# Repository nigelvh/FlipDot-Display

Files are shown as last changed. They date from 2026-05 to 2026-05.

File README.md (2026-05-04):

# FlipDot Display Driver
A driver for a flipdot display I found on eBay. Unfortunately I haven't found what the make/model of the display is. The design was based entirely on reverse engineering the connections.

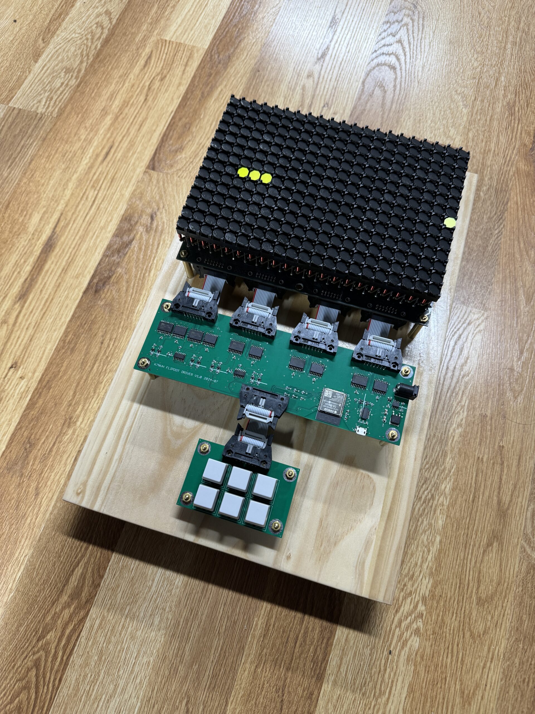
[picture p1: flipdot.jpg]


## Hardware
These are the hardware design files. They're almost certainly terrible. Replicate this device at your own peril.

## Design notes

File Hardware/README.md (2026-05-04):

# Hardware Design
There are two custom PCBs I designed for this project, one simple one just supporting the input buttons, and the other that contains the actual logic and drivers for the flipdot panel.

The ESP32 handles all of the logic for the display, and feeds into the driver shift registers.

The drivers are MIC5841 (Low Side) and MIC5891 (High Side) devices, there's three pairs covering the 21 columns, and then two pairs covering the 14 rows. There are NAND gates on each set that provide an interlock preventing both the high side and low side drivers being active at the same time.

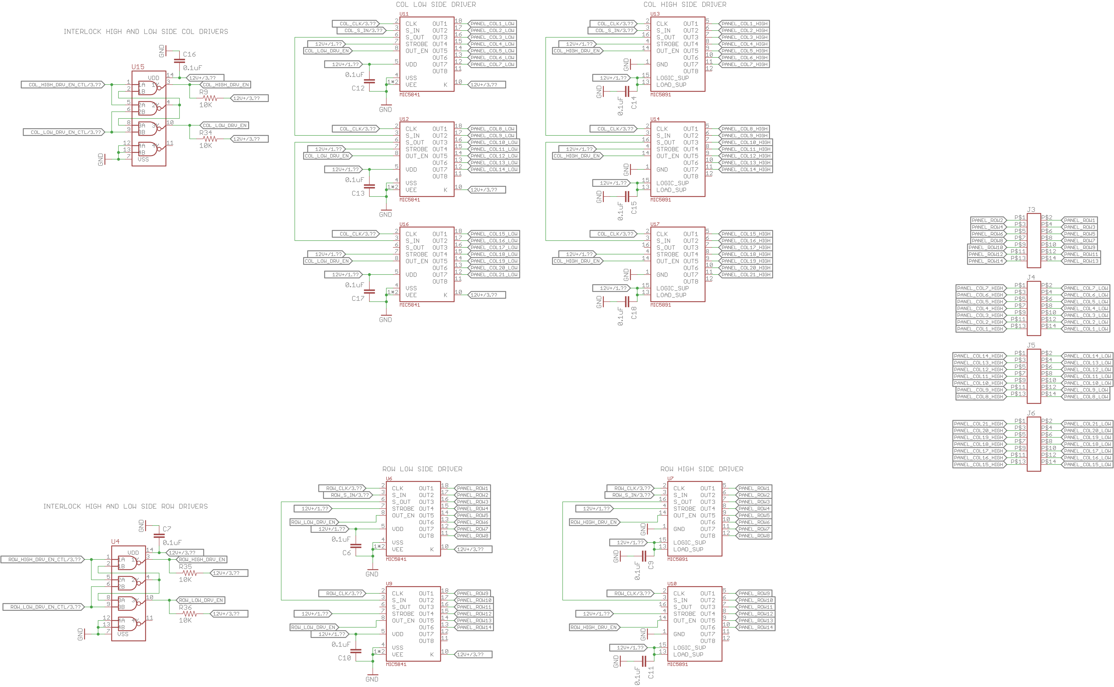
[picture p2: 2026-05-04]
Hardware/Driver/Driver_Schematic_Drivers.png

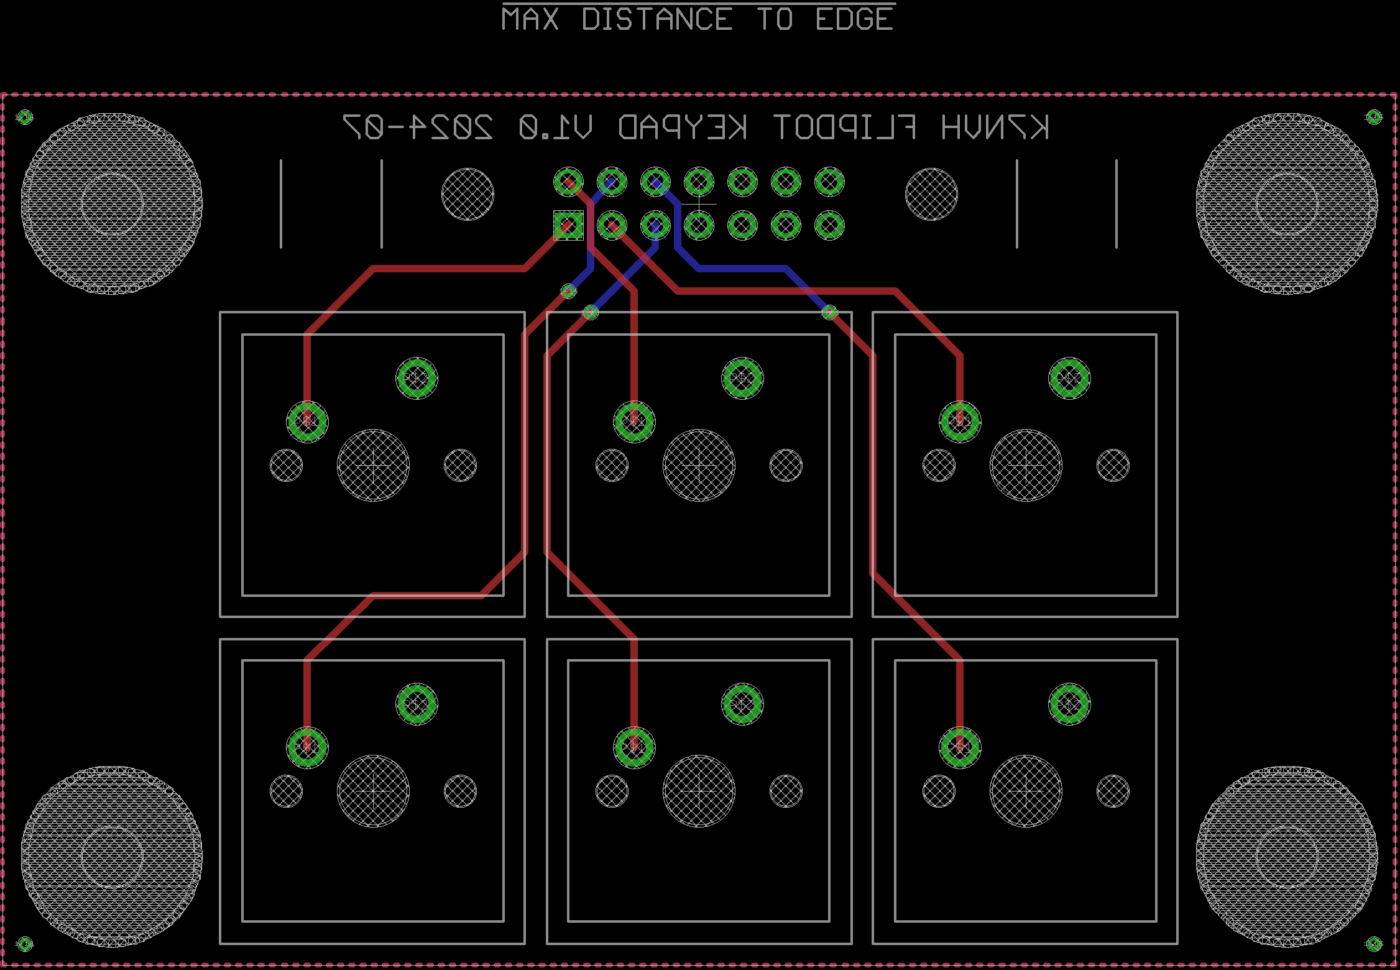
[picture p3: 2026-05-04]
Hardware/Buttons/Button_Board.png

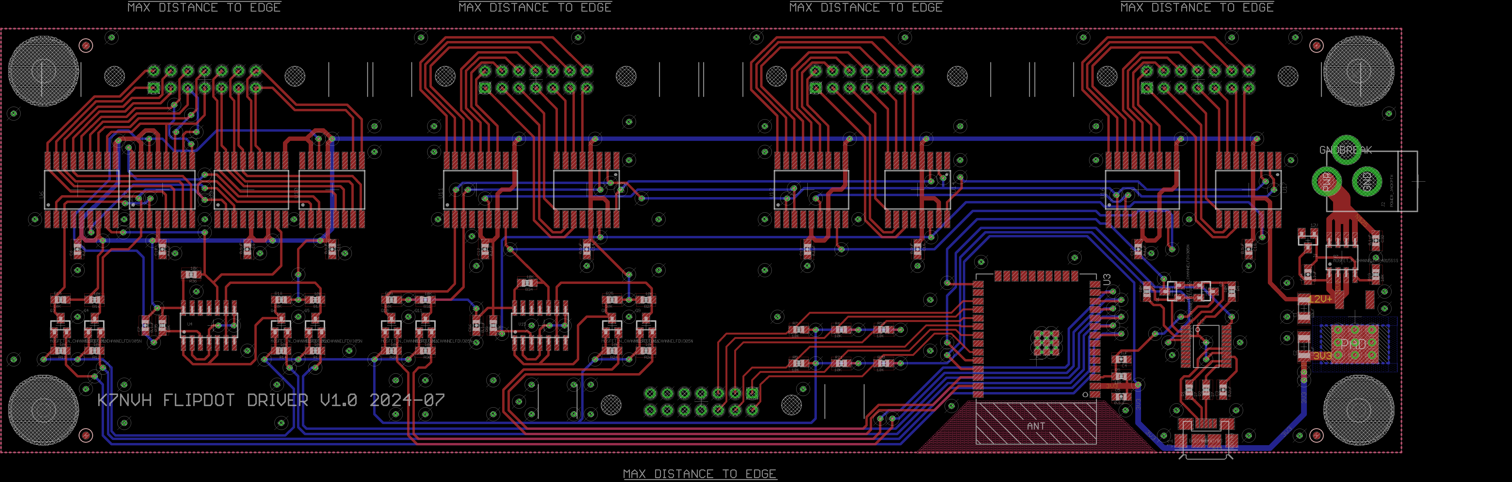
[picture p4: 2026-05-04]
Hardware/Driver/Driver_Board.png

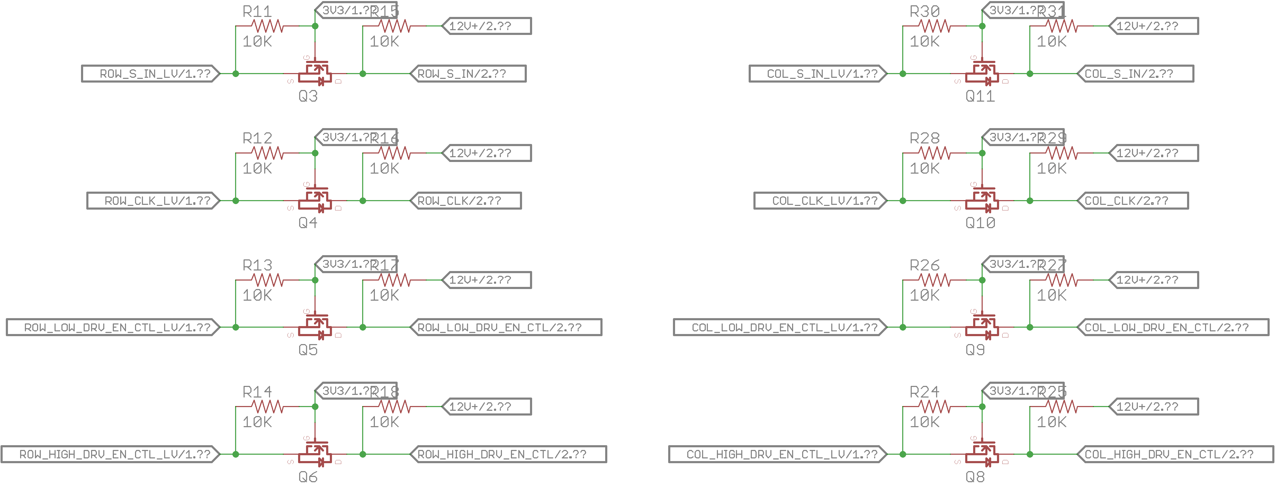
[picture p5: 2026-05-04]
Hardware/Driver/Driver_Schematic_LevelShift.png

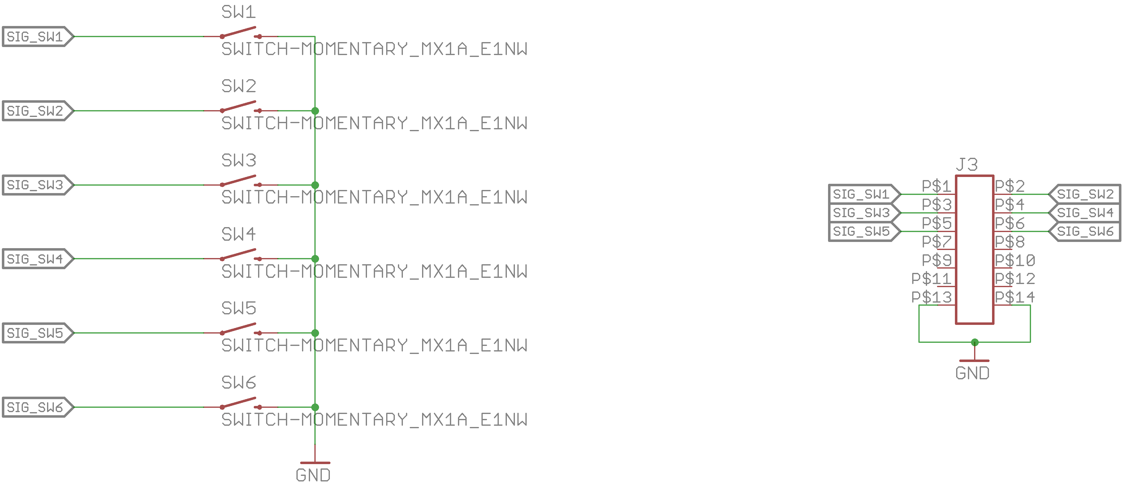
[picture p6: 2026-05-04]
Hardware/Buttons/Button_Schematic.png

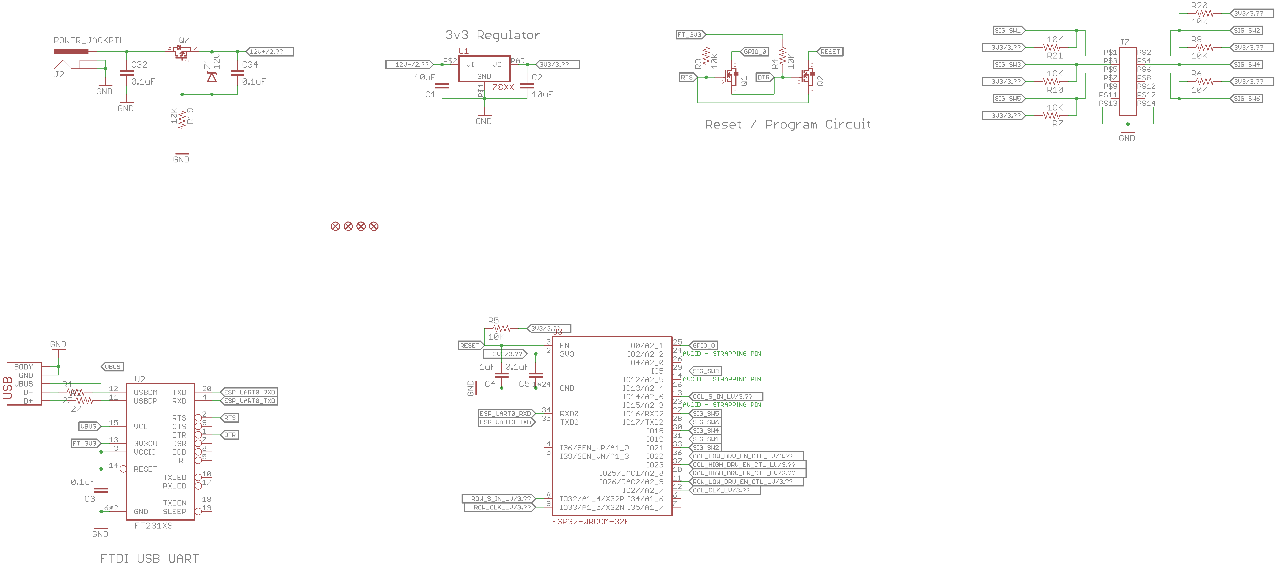
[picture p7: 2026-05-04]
Hardware/Driver/Driver_Schematic_Logic.png

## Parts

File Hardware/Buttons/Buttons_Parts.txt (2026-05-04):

Partlist

Exported from Buttons.sch at 7/29/24 21:16

EAGLE Version 7.7.0 Copyright (c) 1988-2016 CadSoft

Assembly variant: 

Part     Value                      Device                     Package                         Library  Sheet

J3       HEADER-2X7                 HEADER-2X7                 3M-3000SERIES-HEADER-RIGHTANGLE Nigel    1
SW1      SWITCH-MOMENTARY_MX1A_E1NW SWITCH-MOMENTARY_MX1A_E1NW CHERRY_MX1A_E1NW                Nigel    1
SW2      SWITCH-MOMENTARY_MX1A_E1NW SWITCH-MOMENTARY_MX1A_E1NW CHERRY_MX1A_E1NW                Nigel    1
SW3      SWITCH-MOMENTARY_MX1A_E1NW SWITCH-MOMENTARY_MX1A_E1NW CHERRY_MX1A_E1NW                Nigel    1
SW4      SWITCH-MOMENTARY_MX1A_E1NW SWITCH-MOMENTARY_MX1A_E1NW CHERRY_MX1A_E1NW                Nigel    1
SW5      SWITCH-MOMENTARY_MX1A_E1NW SWITCH-MOMENTARY_MX1A_E1NW CHERRY_MX1A_E1NW                Nigel    1
SW6      SWITCH-MOMENTARY_MX1A_E1NW SWITCH-MOMENTARY_MX1A_E1NW CHERRY_MX1A_E1NW                Nigel    1

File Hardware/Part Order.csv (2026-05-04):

Index | DigiKey Part # | Manufacturer Part Number | Manufacturer | Description | Customer Reference | Quantity | Backorder | Unit Price | Extended Price
1 | 1528-5039-ND | 5039 | Adafruit Industries LLC | RELEGENDABLE PLASTIC KEYCAPS FOR |  | 1 | 0 | $4.95000 | $4.95
2 | CH197-ND | MX1A-E1NW | Cherry Americas LLC | SWITCH PUSH SPST-NO 0.01A 12V |  | 6 | 0 | $1.25000 | $7.50
3 | MHR14N-ND | N3314-5302RB | 3M | CONN HEADER R/A 14POS 2.54MM |  | 6 | 0 | $3.17000 | $19.02
4 | 609-4613-1-ND | 10118192-0001LF | Amphenol ICC (FCI) | CONN RCPT USB2.0 MICRO B SMD R/A |  | 1 | 0 | $0.46000 | $0.46
5 | CP-002AH-ND | PJ-002AH | Same Sky (Formerly CUI Devices) | CONN PWR JACK 2X5.5MM SOLDER |  | 1 | 0 | $0.69000 | $0.69
6 | 1965-ESP32-WROOM-32E-H4CT-ND | ESP32-WROOM-32E-H4 | Espressif Systems | RF TXRX MOD BT WIFI TH SMD |  | 1 | 0 | $2.68000 | $2.68
7 | 768-1129-1-ND | FT231XS-R | FTDI, Future Technology Devices International Ltd | IC USB SERIAL FULL UART 20SSOP |  | 1 | 0 | $2.34000 | $2.34
8 | 3365/14300SF-DS-ND | 3365/14 300SF | 3M | CBL RIBN 14COND 0.05 GRAY 300' |  | 10 | 0 | $0.84500 | $8.45
9 | MKC14A-ND | 89114-0101 | 3M | CONN RCPT 14P IDC 26-28AWG GOLD |  | 10 | 0 | $1.30400 | $13.04
10 | MKSR14-ND | 3448-89114 | 3M | STRAIN RELIEF 14 POS IDC SOCKET |  | 10 | 0 | $0.58700 | $5.87
11 | 4530-BSS123CT-ND | BSS123 | ANBON SEMICONDUCTOR (INT'L) LIMITED | N-CHANNEL ENHANCEMENT MODE MOSFE |  | 10 | 0 | $0.09500 | $0.95
12 | DMP4015SSS-13DICT-ND | DMP4015SSS-13 | Diodes Incorporated | MOSFET P-CH 40V 9.1A 8SO |  | 1 | 0 | $0.79000 | $0.79
13 | 31-AZ1117D-3.3TRE1CT-ND | AZ1117D-3.3TRE1 | Diodes Incorporated | IC REG LINEAR 3.3V 1A TO252-3 |  | 1 | 0 | $0.40000 | $0.40
14 | 311-27.0HRCT-ND | RC0603FR-0727RL | YAGEO | RES 27 OHM 1% 1/10W 0603 |  | 10 | 0 | $0.01900 | $0.19
15 | 311-10.0KHRCT-ND | RC0603FR-0710KL | YAGEO | RES 10K OHM 1% 1/10W 0603 |  | 50 | 0 | $0.01120 | $0.56
16 | 1276-1075-1-ND | CL31A106KAHNNNE | Samsung Electro-Mechanics | CAP CER 10UF 25V X5R 1206 |  | 2 | 0 | $0.19000 | $0.38
17 | 1276-1184-1-ND | CL10B105KA8NNNC | Samsung Electro-Mechanics | CAP CER 1UF 25V X7R 0603 |  | 1 | 0 | $0.10000 | $0.10
18 | 1276-1935-1-ND | CL10B104KB8NNWC | Samsung Electro-Mechanics | CAP CER 0.1UF 50V X7R 0603 |  | 20 | 0 | $0.01800 | $0.36
19 | 1727-2951-1-ND | HEF4093BT,653 | Nexperia USA Inc. | IC GATE NAND SCHMIT 4CH 2IN 14SO |  | 2 | 0 | $0.41000 | $0.82
20 | MMBZ5242BLT3GOSCT-ND | MMBZ5242BLT3G | onsemi | DIODE ZENER 12V 225MW SOT23-3 |  | 1 | 0 | $0.14000 | $0.14
21 | 576-1308-1-ND | MIC5841YWM-TR | Microchip Technology | IC PWR DRIVER BIPOLAR 1:8 18SOP |  | 5 | 0 | $5.01000 | $25.05
22 | 576-1311-1-ND | MIC5891YWM-TR | Microchip Technology | IC PWR DRIVER BIPOLAR 1:8 16SOIC |  | 5 | 0 | $3.78000 | $18.90
 |  |  |  |  |  |  |  | Subtotal | $113.64

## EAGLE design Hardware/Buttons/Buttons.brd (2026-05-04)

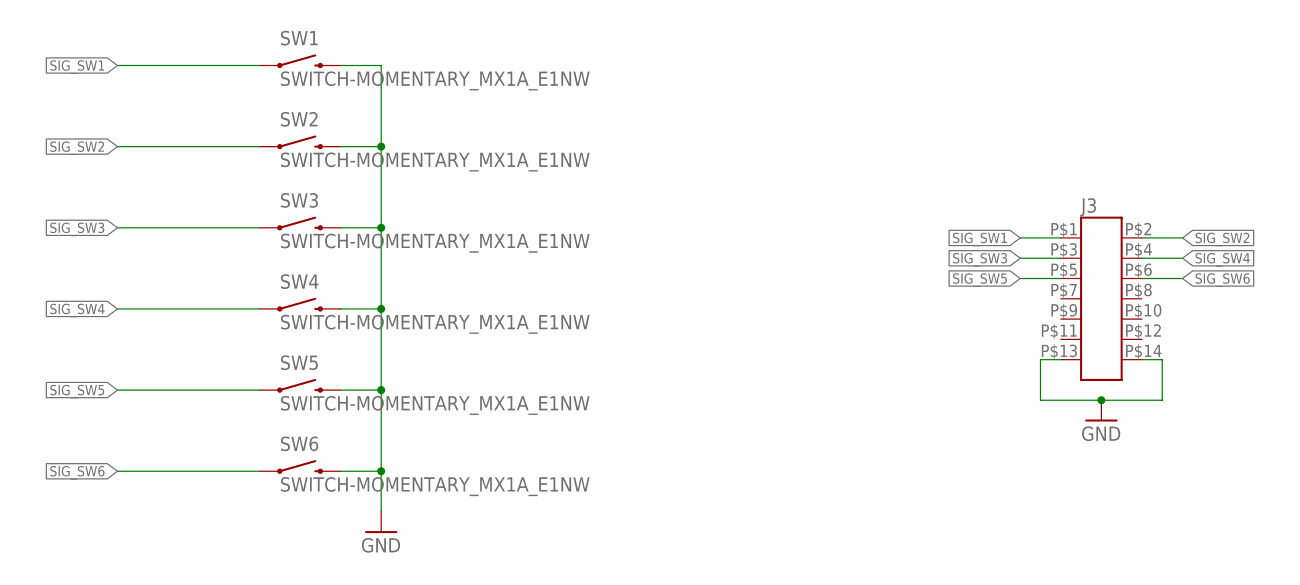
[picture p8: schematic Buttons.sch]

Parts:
J3: HEADER-2X7; 3M-3000SERIES-HEADER-RIGHTANGLE
SW1, SW2, SW3, SW4, SW5, SW6: SWITCH-MOMENTARY_MX1A_E1NW; CHERRY_MX1A_E1NW

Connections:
GND: J3.P$13 (13), J3.P$14 (14), SW1.P$2 (2), SW2.P$2 (2), SW3.P$2 (2), SW4.P$2 (2), SW5.P$2 (2), SW6.P$2 (2)
SIG_SW1: J3.P$1 (1), SW1.P$1 (1)
SIG_SW2: J3.P$2 (2), SW2.P$1 (1)
SIG_SW3: J3.P$3 (3), SW3.P$1 (1)
SIG_SW4: J3.P$4 (4), SW4.P$1 (1)
SIG_SW5: J3.P$5 (5), SW5.P$1 (1)
SIG_SW6: J3.P$6 (6), SW6.P$1 (1)

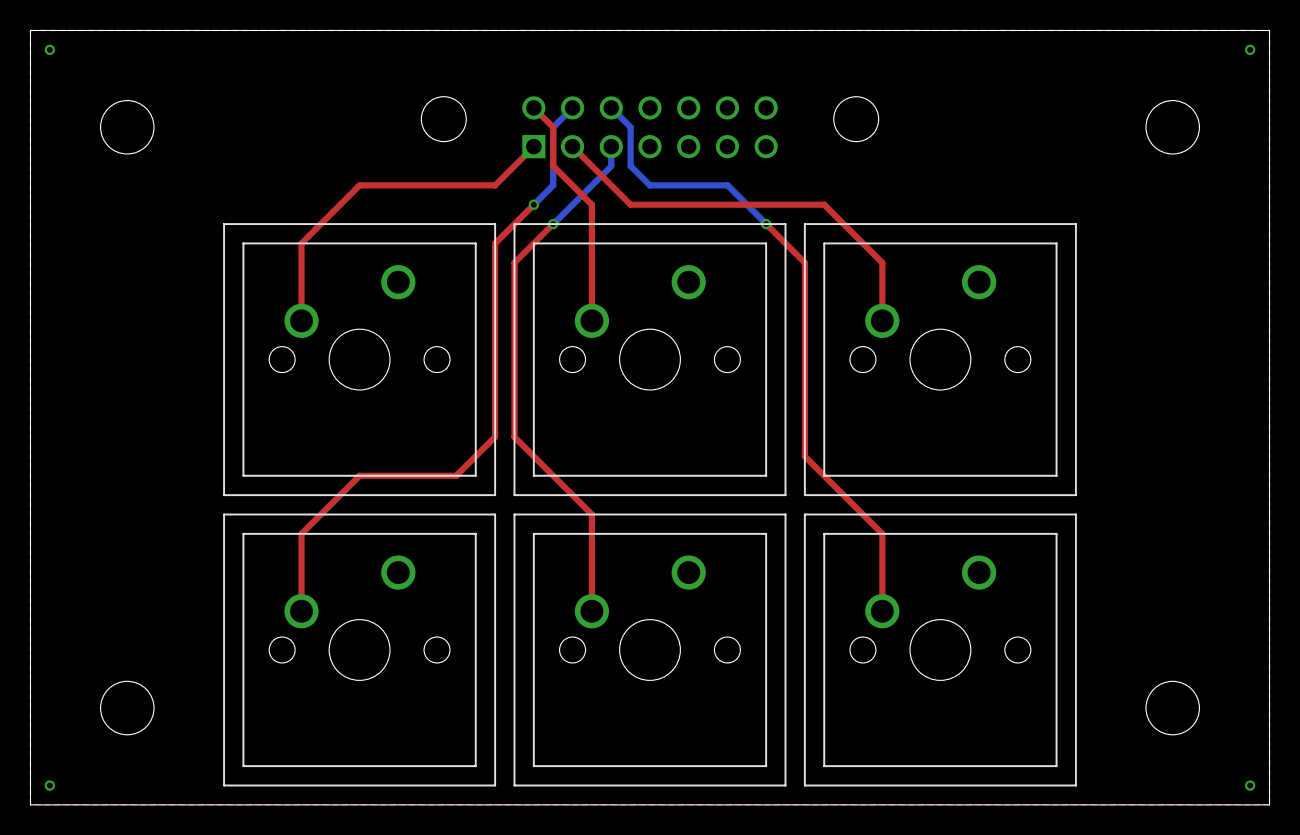
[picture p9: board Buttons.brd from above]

Board: 2 copper layers, 81.3 x 50.8 mm, 7 parts (0 on the bottom side), 7 nets.

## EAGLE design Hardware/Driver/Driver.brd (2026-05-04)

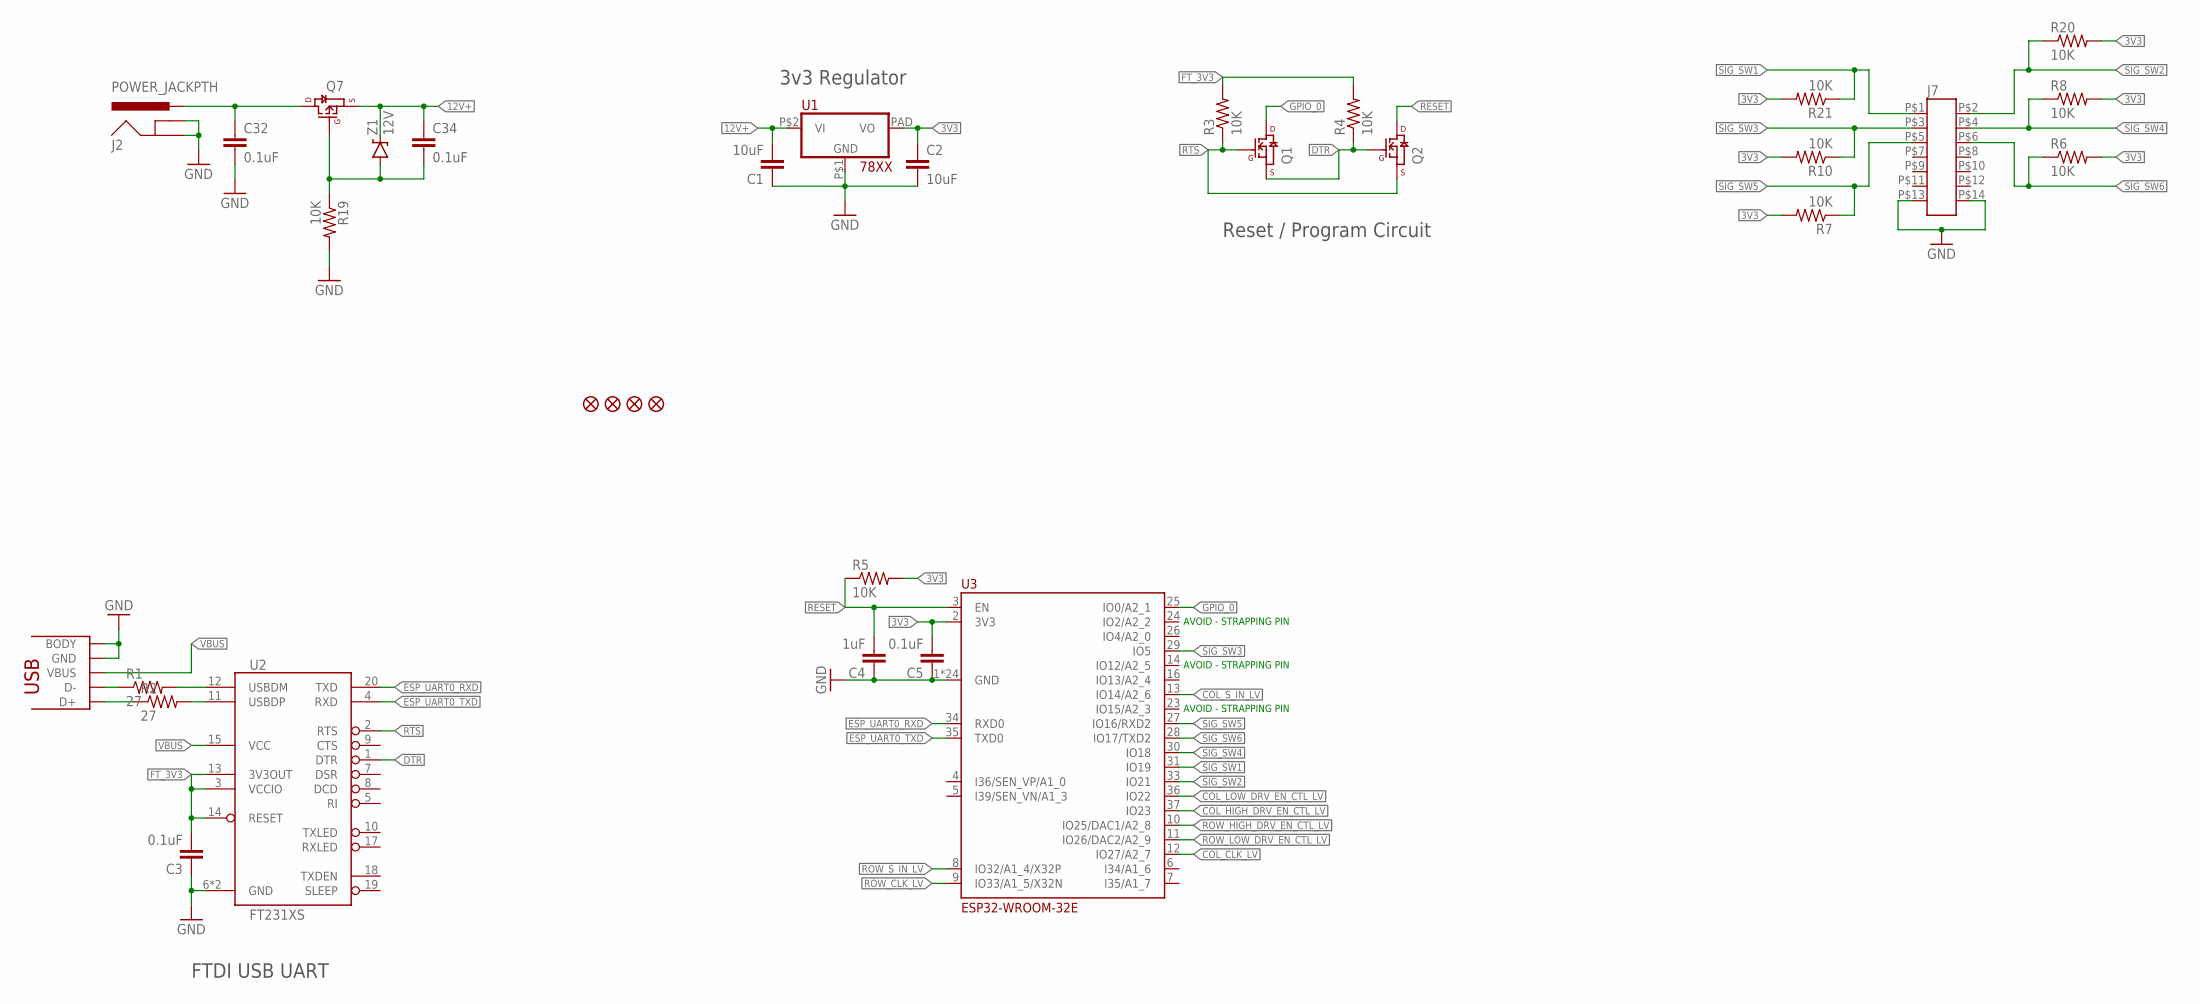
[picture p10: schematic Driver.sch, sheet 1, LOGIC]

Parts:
C1, C2: 10uF; 1206
C3, C5, C32, C34: 0.1uF; 0603-CAP
C4: 1uF; 0603-CAP
FID1, FID2, FID3, FID4: FIDUCIAL
J1: USB-MICROB; USB-MICROB-10118192
J2: POWER_JACKPTH; POWER_JACK_PTH
J7: HEADER-2X7; 3M-3000SERIES-HEADER-RIGHTANGLE
Q1, Q2: MOSFET_N_CHANNELFDV305N; SOT-23
Q7: MOSFET_P_CHANNELDMP4015SSS; SO08
R1, R2: 27; 0603-RES
R3, R4, R5, R6, R7, R8, R10, R19, R20, R21: 10K; 0603-RES
U1: 7805AZ1117_TO252; DPAK-3
U2: FT231XS; SSOP-20
U3: ESP32-WROOM-32E
Z1: 12V; SOT-23

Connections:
3V3: C2.1, C5.2, R5.2, R6.2, R7.2, R8.2, R10.2, R20.2, R21.2, U1.PAD (VO), U3.2 (3V3); also elsewhere on the board
12V+: C1.2, C34.1, Q7.1 (S), Q7.2 (S), Q7.3 (S), U1.P$2 (VI), Z1.3 (C); also elsewhere on the board
COL_CLK_LV: U3.12 (IO27/A2_7); also elsewhere on the board
COL_HIGH_DRV_EN_CTL_LV: U3.37 (IO23); also elsewhere on the board
COL_LOW_DRV_EN_CTL_LV: U3.36 (IO22); also elsewhere on the board
COL_S_IN_LV: U3.13 (IO14/A2_6); also elsewhere on the board
DTR: Q1.2 (S), Q2.1 (G), R4.1, U2.1 (DTR)
ESP_UART0_RXD: U2.20 (TXD), U3.34 (RXD0)
ESP_UART0_TXD: U2.4 (RXD), U3.35 (TXD0)
FT_3V3: C3.2, R3.2, R4.2, U2.3 (VCCIO), U2.13 (3V3OUT), U2.14 (RESET)
GND: C1.1, C2.2, C3.1, C4.1, C5.1, C32.2, J1.5 (GND), J1.BODY@1 (BODY), J1.BODY@2 (BODY), J1.BODY@3 (BODY), J1.BODY@4 (BODY), J1.BODY@5 (BODY), J1.BODY@6 (BODY), J2.GND, J2.GNDBREAK, J7.P$13 (13), J7.P$14 (14), R19.2, U1.P$1 (GND), U2.6 (GND), U2.16 (GND), U3.1 (GND), U3.15 (GND), U3.38 (GND), U3.P$1 (GND), U3.P$2 (GND), U3.P$3 (GND), U3.P$4 (GND), U3.P$5 (GND), U3.P$6 (GND), U3.P$7 (GND), U3.P$8 (GND), U3.P$9 (GND), U3.P$10 (GND), U3.P$11 (GND), U3.P$12 (GND), U3.PAD@1 (GND), U3.PAD@2 (GND), U3.PAD@3 (GND), U3.PAD@4 (GND), U3.PAD@5 (GND), U3.PAD@6 (GND), U3.PAD@7 (GND), U3.PAD@8 (GND), U3.PAD@9 (GND); also elsewhere on the board
GPIO_0: Q1.3 (D), U3.25 (IO0/A2_1)
unnamed: J1.2 (D-), R1.1
unnamed: J1.3 (D+), R2.1
unnamed: R2.2, U2.11 (USBDP)
unnamed: R1.2, U2.12 (USBDM)
unnamed: C32.1, J2.PWR, Q7.5 (D), Q7.6 (D), Q7.7 (D), Q7.8 (D)
unnamed: C34.2, Q7.4 (G), R19.1, Z1.1 (A)
RESET: C4.2, Q2.3 (D), R5.1, U3.3 (EN)
ROW_CLK_LV: U3.9 (IO33/A1_5/X32N); also elsewhere on the board
ROW_HIGH_DRV_EN_CTL_LV: U3.10 (IO25/DAC1/A2_8); also elsewhere on the board
ROW_LOW_DRV_EN_CTL_LV: U3.11 (IO26/DAC2/A2_9); also elsewhere on the board
ROW_S_IN_LV: U3.8 (IO32/A1_4/X32P); also elsewhere on the board
RTS: Q1.1 (G), Q2.2 (S), R3.1, U2.2 (RTS)
SIG_SW1: J7.P$1 (1), R21.1, U3.31 (IO19)
SIG_SW2: J7.P$2 (2), R20.1, U3.33 (IO21)
SIG_SW3: J7.P$3 (3), R10.1, U3.29 (IO5)
SIG_SW4: J7.P$4 (4), R8.1, U3.30 (IO18)
SIG_SW5: J7.P$5 (5), R7.1, U3.27 (IO16/RXD2)
SIG_SW6: J7.P$6 (6), R6.1, U3.28 (IO17/TXD2)
VBUS: J1.1 (VBUS), U2.15 (VCC)

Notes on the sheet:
FTDI USB UART
3v3 Regulator
Reset / Program Circuit
AVOID - STRAPPING PIN

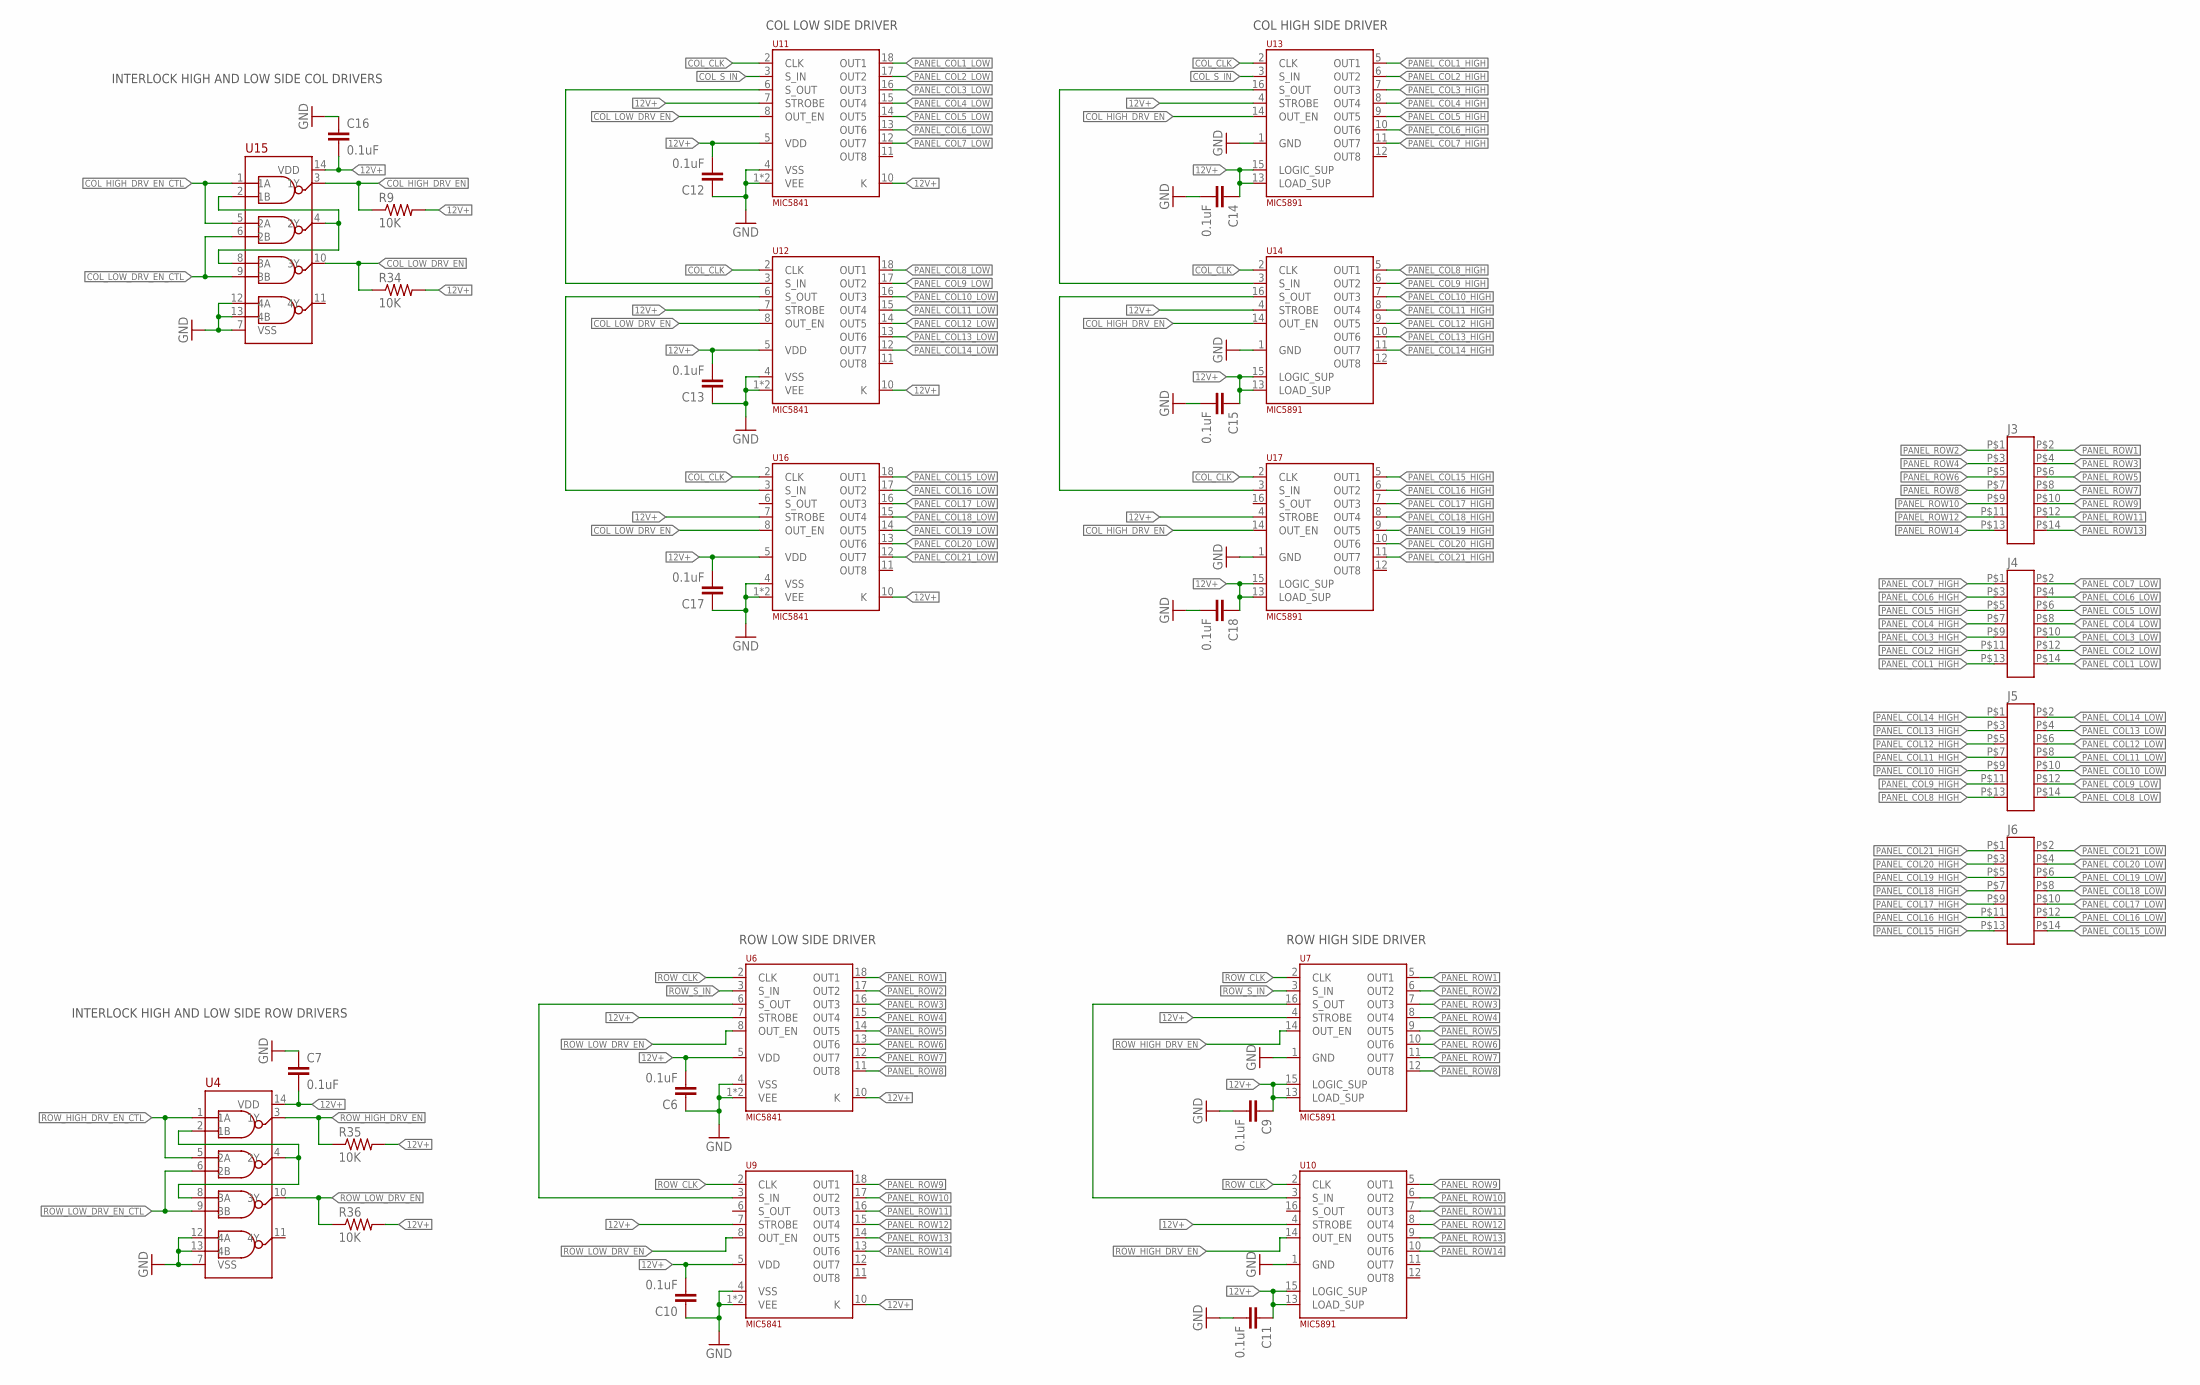
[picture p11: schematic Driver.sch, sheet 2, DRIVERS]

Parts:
C6, C7, C9, C10, C11, C12, C13, C14, C15, C16, C17, C18: 0.1uF; 0603-CAP
J3, J4, J5, J6: HEADER-2X7; 3M-3000SERIES-HEADER-RIGHTANGLE
R9, R34, R35, R36: 10K; 0603-RES
U4, U15: HEF4093B; SOIC-14
U6, U9, U11, U12, U16: MIC5841; SOIC-18-WIDE
U7, U10, U13, U14, U17: MIC5891; SOIC-16-WIDE

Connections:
12V+: C6.2, C7.2, C9.1, C10.2, C11.1, C12.2, C13.2, C14.1, C15.1, C16.2, C17.2, C18.1, R9.2, R34.2, R35.2, R36.2, U4.14 (VDD), U6.5 (VDD), U6.7 (STROBE), U6.10 (K), U7.4 (STROBE), U7.13 (LOAD_SUP), U7.15 (LOGIC_SUP), U9.5 (VDD), U9.7 (STROBE), U9.10 (K), U10.4 (STROBE), U10.13 (LOAD_SUP), U10.15 (LOGIC_SUP), U11.5 (VDD), U11.7 (STROBE), U11.10 (K), U12.5 (VDD), U12.7 (STROBE), U12.10 (K), U13.4 (STROBE), U13.13 (LOAD_SUP), U13.15 (LOGIC_SUP), U14.4 (STROBE), U14.13 (LOAD_SUP), U14.15 (LOGIC_SUP), U15.14 (VDD), U16.5 (VDD), U16.7 (STROBE), U16.10 (K), U17.4 (STROBE), U17.13 (LOAD_SUP), U17.15 (LOGIC_SUP); also elsewhere on the board
COL_CLK: U11.2 (CLK), U12.2 (CLK), U13.2 (CLK), U14.2 (CLK), U16.2 (CLK), U17.2 (CLK); also elsewhere on the board
COL_HIGH_DRV_EN: R9.1, U13.14 (OUT_EN), U14.14 (OUT_EN), U15.3 (1Y), U17.14 (OUT_EN)
COL_HIGH_DRV_EN_CTL: U15.1 (1A), U15.5 (2A); also elsewhere on the board
COL_LOW_DRV_EN: R34.1, U11.8 (OUT_EN), U12.8 (OUT_EN), U15.10 (3Y), U16.8 (OUT_EN)
COL_LOW_DRV_EN_CTL: U15.6 (2B), U15.9 (3B); also elsewhere on the board
COL_S_IN: U11.3 (S_IN), U13.3 (S_IN); also elsewhere on the board
GND: C6.1, C7.1, C9.2, C10.1, C11.2, C12.1, C13.1, C14.2, C15.2, C16.1, C17.1, C18.2, U4.7 (VSS), U4.12 (4A), U4.13 (4B), U6.1 (VEE), U6.4 (VSS), U6.9 (VEE), U7.1 (GND), U9.1 (VEE), U9.4 (VSS), U9.9 (VEE), U10.1 (GND), U11.1 (VEE), U11.4 (VSS), U11.9 (VEE), U12.1 (VEE), U12.4 (VSS), U12.9 (VEE), U13.1 (GND), U14.1 (GND), U15.7 (VSS), U15.12 (4A), U15.13 (4B), U16.1 (VEE), U16.4 (VSS), U16.9 (VEE), U17.1 (GND); also elsewhere on the board
unnamed: U6.6 (S_OUT), U9.3 (S_IN)
unnamed: U4.2 (1B), U4.4 (2Y), U4.8 (3A)
unnamed: U7.16 (S_OUT), U10.3 (S_IN)
unnamed: U11.6 (S_OUT), U12.3 (S_IN)
unnamed: U13.16 (S_OUT), U14.3 (S_IN)
unnamed: U15.2 (1B), U15.4 (2Y), U15.8 (3A)
unnamed: U12.6 (S_OUT), U16.3 (S_IN)
unnamed: U14.16 (S_OUT), U17.3 (S_IN)
PANEL_COL1_HIGH: J4.P$13 (13), U13.5 (OUT1)
PANEL_COL1_LOW: J4.P$14 (14), U11.18 (OUT1)
PANEL_COL2_HIGH: J4.P$11 (11), U13.6 (OUT2)
PANEL_COL2_LOW: J4.P$12 (12), U11.17 (OUT2)
PANEL_COL3_HIGH: J4.P$9 (9), U13.7 (OUT3)
PANEL_COL3_LOW: J4.P$10 (10), U11.16 (OUT3)
PANEL_COL4_HIGH: J4.P$7 (7), U13.8 (OUT4)
PANEL_COL4_LOW: J4.P$8 (8), U11.15 (OUT4)
PANEL_COL5_HIGH: J4.P$5 (5), U13.9 (OUT5)
PANEL_COL5_LOW: J4.P$6 (6), U11.14 (OUT5)
PANEL_COL6_HIGH: J4.P$3 (3), U13.10 (OUT6)
PANEL_COL6_LOW: J4.P$4 (4), U11.13 (OUT6)
PANEL_COL7_HIGH: J4.P$1 (1), U13.11 (OUT7)
PANEL_COL7_LOW: J4.P$2 (2), U11.12 (OUT7)
PANEL_COL8_HIGH: J5.P$13 (13), U14.5 (OUT1)
PANEL_COL8_LOW: J5.P$14 (14), U12.18 (OUT1)
PANEL_COL9_HIGH: J5.P$11 (11), U14.6 (OUT2)
PANEL_COL9_LOW: J5.P$12 (12), U12.17 (OUT2)
PANEL_COL10_HIGH: J5.P$9 (9), U14.7 (OUT3)
PANEL_COL10_LOW: J5.P$10 (10), U12.16 (OUT3)
PANEL_COL11_HIGH: J5.P$7 (7), U14.8 (OUT4)
PANEL_COL11_LOW: J5.P$8 (8), U12.15 (OUT4)
PANEL_COL12_HIGH: J5.P$5 (5), U14.9 (OUT5)
PANEL_COL12_LOW: J5.P$6 (6), U12.14 (OUT5)
PANEL_COL13_HIGH: J5.P$3 (3), U14.10 (OUT6)
PANEL_COL13_LOW: J5.P$4 (4), U12.13 (OUT6)
PANEL_COL14_HIGH: J5.P$1 (1), U14.11 (OUT7)
PANEL_COL14_LOW: J5.P$2 (2), U12.12 (OUT7)
PANEL_COL15_HIGH: J6.P$13 (13), U17.5 (OUT1)
PANEL_COL15_LOW: J6.P$14 (14), U16.18 (OUT1)
PANEL_COL16_HIGH: J6.P$11 (11), U17.6 (OUT2)
PANEL_COL16_LOW: J6.P$12 (12), U16.17 (OUT2)
PANEL_COL17_HIGH: J6.P$9 (9), U17.7 (OUT3)
PANEL_COL17_LOW: J6.P$10 (10), U16.16 (OUT3)
PANEL_COL18_HIGH: J6.P$7 (7), U17.8 (OUT4)
PANEL_COL18_LOW: J6.P$8 (8), U16.15 (OUT4)
PANEL_COL19_HIGH: J6.P$5 (5), U17.9 (OUT5)
PANEL_COL19_LOW: J6.P$6 (6), U16.14 (OUT5)
PANEL_COL20_HIGH: J6.P$3 (3), U17.10 (OUT6)
PANEL_COL20_LOW: J6.P$4 (4), U16.13 (OUT6)
PANEL_COL21_HIGH: J6.P$1 (1), U17.11 (OUT7)
PANEL_COL21_LOW: J6.P$2 (2), U16.12 (OUT7)
PANEL_ROW1: J3.P$2 (2), U6.18 (OUT1), U7.5 (OUT1)
PANEL_ROW2: J3.P$1 (1), U6.17 (OUT2), U7.6 (OUT2)
PANEL_ROW3: J3.P$4 (4), U6.16 (OUT3), U7.7 (OUT3)
PANEL_ROW4: J3.P$3 (3), U6.15 (OUT4), U7.8 (OUT4)
PANEL_ROW5: J3.P$6 (6), U6.14 (OUT5), U7.9 (OUT5)
PANEL_ROW6: J3.P$5 (5), U6.13 (OUT6), U7.10 (OUT6)
PANEL_ROW7: J3.P$8 (8), U6.12 (OUT7), U7.11 (OUT7)
PANEL_ROW8: J3.P$7 (7), U6.11 (OUT8), U7.12 (OUT8)
PANEL_ROW9: J3.P$10 (10), U9.18 (OUT1), U10.5 (OUT1)
PANEL_ROW10: J3.P$9 (9), U9.17 (OUT2), U10.6 (OUT2)
PANEL_ROW11: J3.P$12 (12), U9.16 (OUT3), U10.7 (OUT3)
PANEL_ROW12: J3.P$11 (11), U9.15 (OUT4), U10.8 (OUT4)
PANEL_ROW13: J3.P$14 (14), U9.14 (OUT5), U10.9 (OUT5)
PANEL_ROW14: J3.P$13 (13), U9.13 (OUT6), U10.10 (OUT6)
ROW_CLK: U6.2 (CLK), U7.2 (CLK), U9.2 (CLK), U10.2 (CLK); also elsewhere on the board
ROW_HIGH_DRV_EN: R35.1, U4.3 (1Y), U7.14 (OUT_EN), U10.14 (OUT_EN)
ROW_HIGH_DRV_EN_CTL: U4.1 (1A), U4.5 (2A); also elsewhere on the board
ROW_LOW_DRV_EN: R36.1, U4.10 (3Y), U6.8 (OUT_EN), U9.8 (OUT_EN)
ROW_LOW_DRV_EN_CTL: U4.6 (2B), U4.9 (3B); also elsewhere on the board
ROW_S_IN: U6.3 (S_IN), U7.3 (S_IN); also elsewhere on the board

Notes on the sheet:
INTERLOCK HIGH AND LOW SIDE ROW DRIVERS
ROW LOW SIDE DRIVER
ROW HIGH SIDE DRIVER
COL LOW SIDE DRIVER
COL HIGH SIDE DRIVER
INTERLOCK HIGH AND LOW SIDE COL DRIVERS

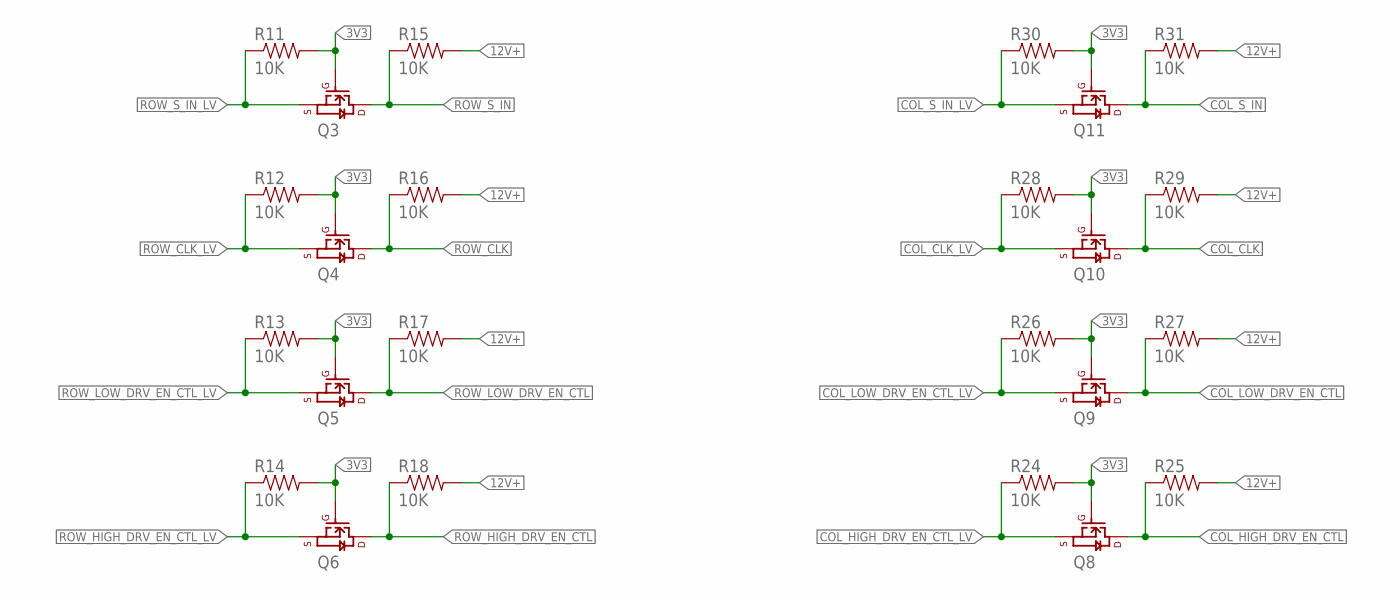
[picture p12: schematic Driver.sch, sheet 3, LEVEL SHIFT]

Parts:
Q3, Q4, Q5, Q6, Q8, Q9, Q10, Q11: MOSFET_N_CHANNELFDV305N; SOT-23
R11, R12, R13, R14, R15, R16, R17, R18, R24, R25, R26, R27, R28, R29, R30, R31: 10K; 0603-RES

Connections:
3V3: Q3.1 (G), Q4.1 (G), Q5.1 (G), Q6.1 (G), Q8.1 (G), Q9.1 (G), Q10.1 (G), Q11.1 (G), R11.2, R12.2, R13.2, R14.2, R24.2, R26.2, R28.2, R30.2; also elsewhere on the board
12V+: R15.2, R16.2, R17.2, R18.2, R25.2, R27.2, R29.2, R31.2; also elsewhere on the board
COL_CLK: Q10.3 (D), R29.1; also elsewhere on the board
COL_CLK_LV: Q10.2 (S), R28.1; also elsewhere on the board
COL_HIGH_DRV_EN_CTL: Q8.3 (D), R25.1; also elsewhere on the board
COL_HIGH_DRV_EN_CTL_LV: Q8.2 (S), R24.1; also elsewhere on the board
COL_LOW_DRV_EN_CTL: Q9.3 (D), R27.1; also elsewhere on the board
COL_LOW_DRV_EN_CTL_LV: Q9.2 (S), R26.1; also elsewhere on the board
COL_S_IN: Q11.3 (D), R31.1; also elsewhere on the board
COL_S_IN_LV: Q11.2 (S), R30.1; also elsewhere on the board
ROW_CLK: Q4.3 (D), R16.1; also elsewhere on the board
ROW_CLK_LV: Q4.2 (S), R12.1; also elsewhere on the board
ROW_HIGH_DRV_EN_CTL: Q6.3 (D), R18.1; also elsewhere on the board
ROW_HIGH_DRV_EN_CTL_LV: Q6.2 (S), R14.1; also elsewhere on the board
ROW_LOW_DRV_EN_CTL: Q5.3 (D), R17.1; also elsewhere on the board
ROW_LOW_DRV_EN_CTL_LV: Q5.2 (S), R13.1; also elsewhere on the board
ROW_S_IN: Q3.3 (D), R15.1; also elsewhere on the board
ROW_S_IN_LV: Q3.2 (S), R11.1; also elsewhere on the board

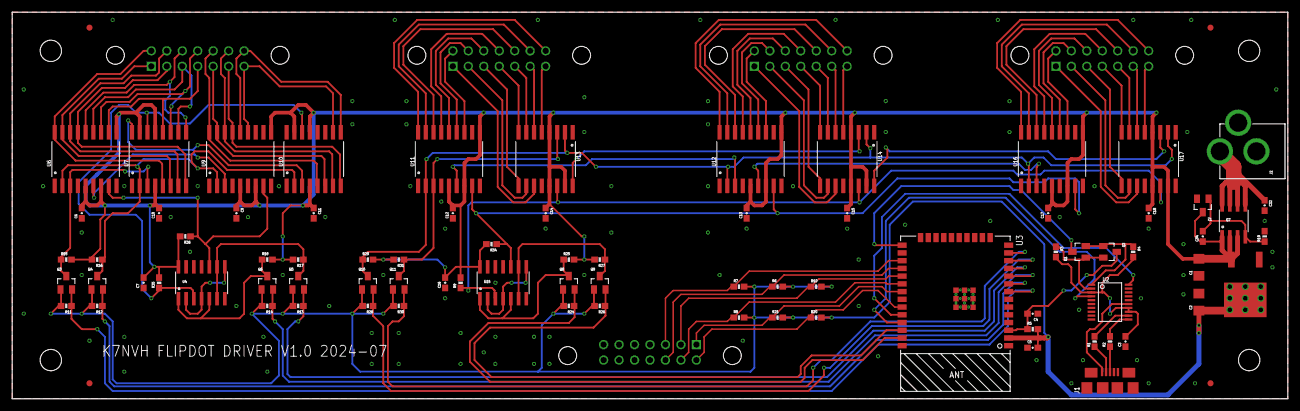
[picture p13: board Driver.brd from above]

Board: 2 copper layers, 209.6 x 63.5 mm, 89 parts (0 on the bottom side), 107 nets.

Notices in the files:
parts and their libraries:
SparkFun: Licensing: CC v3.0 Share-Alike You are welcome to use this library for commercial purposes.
